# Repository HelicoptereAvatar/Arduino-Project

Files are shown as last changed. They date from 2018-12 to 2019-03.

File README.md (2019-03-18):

# Projet Arduino
Helicoptère Avatar

Lien de la phase de finition de l'usinage: https://youtu.be/9hvU3ZJVlw8

Lien du systeme palonnier/axe moteur version 1: https://www.youtube.com/watch?v=DUoeanbGZsc

Lien du système palonnier/axe moteur version2: https://www.youtube.com/watch?v=2ytFxMqF1lg

Lien du test des moteurs brushless après rectification des soudures: https://www.youtube.com/watch?v=3YJs_jeSbtI7

Lien du 1er Test de décollage du bicoptère via Bluetooth: https://www.youtube.com/watch?v=y_h1CxXEg0Y&feature=youtu.be

Lien du 2eme Test de décollage du bicoptère via Bluetooth: https://www.youtube.com/watch?v=23QDOOEaW0g

Lien de l'orientation du sens de rotation du bicoptère via Bluetooth: https://www.youtube.com/watch?v=-SvJQlqzLKM 

Lien du dernier vol avant la présentation, vol parfait: https://www.youtube.com/watch?v=pWN4PxkNXiw&feature=youtu.be

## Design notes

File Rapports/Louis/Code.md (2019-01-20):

/* Here is the code that I used to control the servos and the ESCs via Bluetooth */

#include <Servo.h>
#include<SoftwareSerial.h>
#define RX 10
#define TX 11
SoftwareSerial BlueT(RX,TX);
char Data;
int PWM=190;
int Angled=90;
int Angleg=90;
Servo esc1;   // Création de l'objet permettant le contrôle de l'ESC
Servo esc2;
Servo servo1;
Servo servo2;

void setup() {
   servo1.attach(2);
   servo2.attach(3);
   servo1.write(90);
   servo2.write(90);
   esc1.attach(6); // On attache l'ESC au port numérique 9 (port PWM obligatoire)
   esc2.attach(5);
   delay(15);
   //Serial.begin(9600);
   BlueT.begin(9600);
   // Initialisation de l'ESC
   //  (certains ESC ont besoin d'une "procédure d'initialisation"
   //   pour devenir opérationnels - voir notice)
   esc1.write(0);
   esc2.write(0);
   delay(1000);
   esc1.write(180);
   esc2.write(180);
   delay(1000);
   esc1.write(0);
   esc2.write(0);

   // Quelques informations pour l'utilisateur
   /*Serial.println("Saisir un nombre entre 0 et 179");
   Serial.println("(0 = arret - 179 = vitesse maxi");
   Serial.println(" demarrage a partir de 20)");*/
   }
 
void loop() {
  if (BlueT.available()){
    Data=BlueT.read();
    if(Data=='A'){
      PWM=BlueT.parseInt();
    }
    if (PWM>0){
      esc1.write(PWM);
      esc2.write(PWM+7);
      delay(5);
    }
    else{
      esc1.write(PWM);
      esc2.write(PWM);          
      delay(5);
      }
    if (Data=='D'){ //Angle entre 75deg et 120deg
        Angled=BlueT.parseInt();
        servo1.write(Angled);
        delay(5);
    }
    if (Data=='G'){  //Angle entre 30deg et 120deg
      Angleg=BlueT.parseInt();
      servo2.write(Angleg);
      delay(5);
  }
  }
}

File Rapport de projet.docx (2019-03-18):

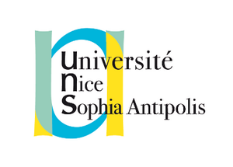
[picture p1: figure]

Rapport de projet

Hélicoptère avatar

Calendini-Clouvel

Encadrant : Monsieur Pascal Masson

Ecole Polytechnique Universitaire de Nice Sophia-Antipolis, 1645 route des Lucioles,

Parc de Sophia Antipolis, 06410 BIOT

# Remerciements

Nous voudrions remercier Monsieur Philippe Duroure (entreprise : 2iADP) pour son aide précieuse dans la réalisation de l’usinage d’une partie du châssis ainsi que Monsieur Xavier Esa (entreprise : DEBARGES) pour nous avoir aidés lors de l’usinage des palonniers.

Nous tenions à remercier particulièrement Monsieur Pascal Masson (enseignant en électronique) ainsi que Monsieur Nassim Abderrahmane pour leurs conseils avisés tout au long de l’avancement du projet.

# Table des matières

# Introduction

Nous présentons dans ce rapport notre projet d’Electronique de deuxième année d’étude. Ce projet consiste à concevoir et réaliser, en binôme, dans un temps imparti, un bicoptère. Nous détaillerons les étapes permettant d’atteindre nos objectifs, à savoir l’envol et la stabilité du système.

We are going to present you in this report our electronic project which goal is to conceive and realise, in pairs and in three months, a dualcopter. You will see all the steps we went through to reach our intent, namely taking off and being stable.

# Matériel utilisé

Afin de pouvoir réaliser ce projet, nous avons utilisé le matériel suivant :

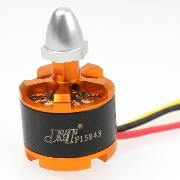
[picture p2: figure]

- 2 moteurs brushless, 920 kv

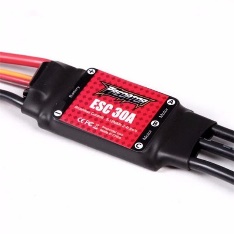
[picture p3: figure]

- 2 ESCs de 30A

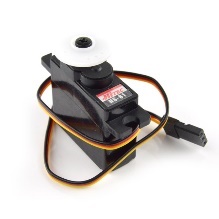
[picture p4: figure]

- 2 servo-moteurs hitech
- 1 châssis dont une partie réalisée sur un centre d’usinage (CNC)

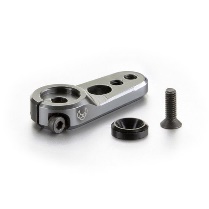
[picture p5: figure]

- 4 palonniers (dont 2 usinés)

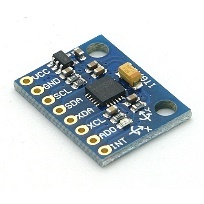
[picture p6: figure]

- 1 accéléromètre/gyroscope GY-521
- 1 carte arduino

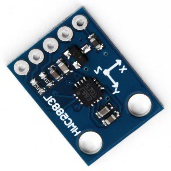
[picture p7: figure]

- 1 magnétomètre

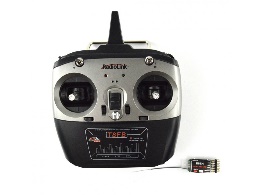
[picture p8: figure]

- 1 émetteur/récepteur radio

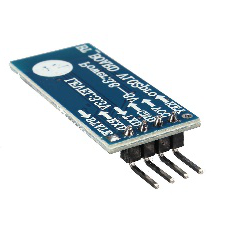
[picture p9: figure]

- 1 module bluetooth

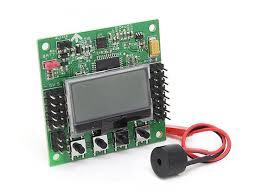
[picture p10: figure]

- 1 carte de contrôle KK2.1.5
- 1 tube en aluminium
- 2 hélices

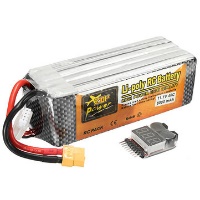
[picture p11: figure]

- 3 batteries Lipo, 3S (12V)
- 1 batterie 5V

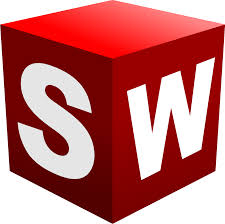
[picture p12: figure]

- Logiciel SolidWorks

# Déroulement du projet

## Conception

Le premier mois, nous avons défini notre stratégie de définition, d'étude et de réalisation, après réflexion nous nous sommes mis d’accord pour diviser le projet en 2 parties, l’électronique et la mécanique. Dans un premier temps nous avons rassemblé les informations nous permettant de comprendre le fonctionnement de ce système et pouvoir appréhender des solutions technologiques répondant aux contraintes.

Après avoir défini les mouvements nécessaires à l’orientation du bicoptère dans l’espace, nous avons dessiné la partie du châssis permettant la rotation des moteurs. Le premier schéma s’est fait sur papier puis sur SolidWorks pour permettre la réalisation sur un centre d’usinage numérique 3axes.

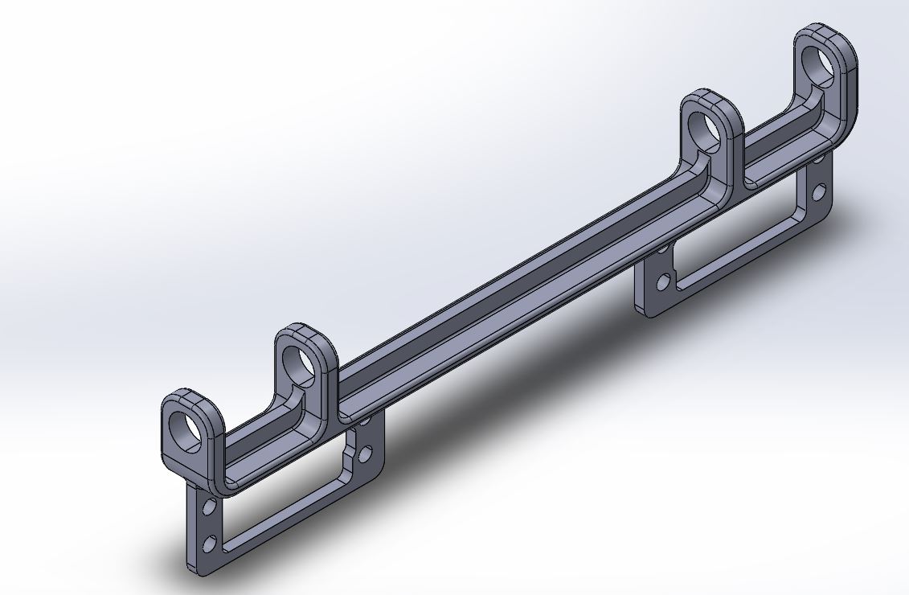
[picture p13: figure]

## Réalisation

### Electronique :

1. Moteurs et servo-moteurs :

Info PWM (Pulse Width Modulation) : Le PWM utilisé doit avoir une fréquence de 50Hz et c’est la durée du temps haut qui permet de coder la vitesse de rotation des moteurs :

- Pour un temps haut de 1000ms les moteurs seront éteints.

- Pour un temps haut de 2000ms les moteurs seront en vitesse max.

Les signaux PWM de 50Hz sont très utilisés en modélisme pour le contrôle de tout type de moteur. En Arduino, la librairie Servo.h permet de générer ces signaux.

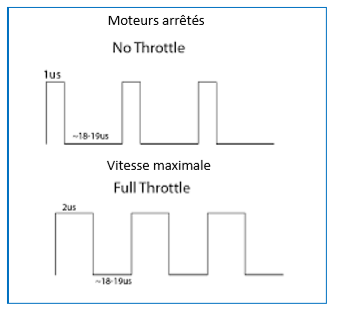
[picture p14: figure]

Nous avons commencé par coder les moteurs brushless et les servo-moteurs mis à notre disposition. Grâce aux éléments de cours ainsi que nos recherches sur internet, nous avons rapidement maitrisé cette technique.

On a ensuite ajouté le module Bluetooth afin de permettre le contrôle à distance de chaque composant.

Une fois les codes mis en commun, nous avons rencontré un premier problème : les servo-moteurs et les moteurs utilisant la même librairie, on ne pouvait contrôler qu’un seul élément à la fois.

Grâce à la documentation Arduino, nous avons compris que cela venait des ports de sortie. Il suffisait juste de brancher les composants sur des ports bien choisis.

2. Asservissement :

Le PID est un système de contrôle permettant la stabilisation de notre bicoptère. Celui-ci agit en fonction des valeurs d’angle que l’accéléromètre et le magnétomètre peuvent fournir.

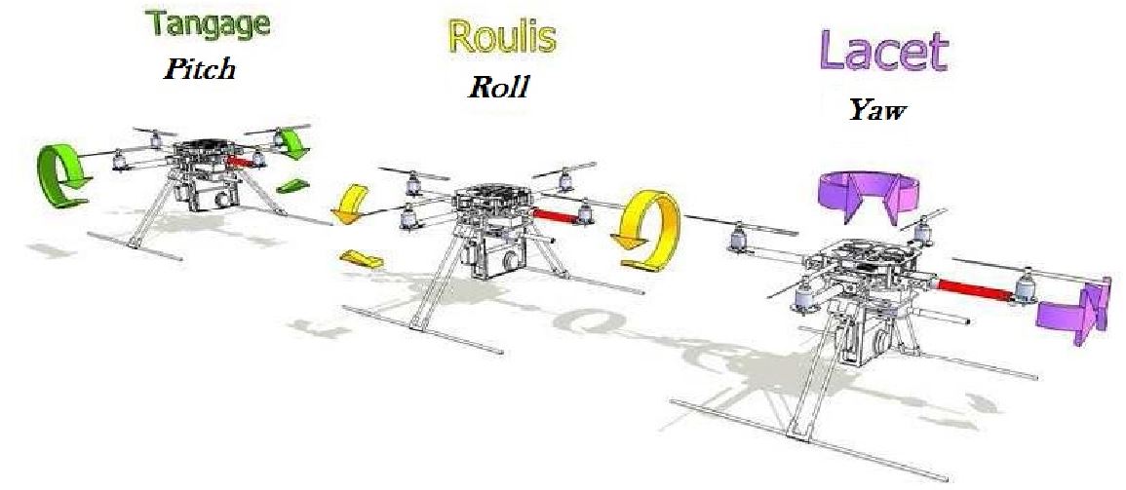
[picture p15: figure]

Dans notre cas, l’axe x correspond au Roulis, l’axe y au Tangage et l’axe z au Lacet

La stabilisation doit se faire suivant l’axe x, y et z. Pour ce qui est des axes x et y nous avons utilisé l’accéléromètre. Celui nous permet d’avoir l’angle (entre 0 et 90°) que fait le bicoptère avec le sol suivant ces 2 axes. Ces informations sont ensuite envoyées au PID et celui-ci va permettre la stabilisation, grâce à trois asservissements :

• Proportionnel

• Intégral

• Dérivé

L’asservissement proportionnel est le plus important, les autres asservissements permettent de gérer les erreurs afin que la stabilisation soit optimale.

Dans notre cas, pour l’axe x, le PID va agir sur les moteurs. En effet, lorsque le bicoptère va pencher vers la gauche, le moteur de gauche va accélérer en conséquence afin de le remettre droit, et inversement.

Pour l’axe y, le PID agit sur les servo-moteurs. Lorsque le bicoptère penche vers l’avant, les servos s’orientent vers l’arrière, ce qui permet à ce dernier de rester parallèle au sol.

La stabilisation sur ces 2 axes a été correctement codée.

Pour la stabilisation suivant z, le PID va recevoir un angle du magnétomètre et non de l’accéléromètre (celui-ci ne permet pas d’avoir la valeur de l’angle du lacet).

Le magnétomètre est en réalité une boussole, le zéro correspond au Nord puis en fonction de comment on tourne notre magnétomètre, l’angle varie entre 0 et 360°.

Pour cet axe z, le PID va agir sur les servos encore une fois mais dans ce cas, il les orientera dans le sens opposé, afin que la rotation soit compensée et que le bicoptère ne tourne pas sur lui-même.

La stabilisation suivant z n’a pas pu se faire car cela devenait trop compliqué pour nous.

### Mécanique :

Après avoir dessiné sur le logiciel de CAO (Conception assistée par Ordinateur ici SolidWorks) la partie du châssis à usiner dans un bloc d’aluminium il faut maintenant ouvrir ce document dans un logiciel de FAO (Fabrication Assistée par Ordinateur ici TopSolid) afin de générer un parcours d’outils pour chaque phase de l’usinage (Ebauche, Semi-finition, Finition) qui sera envoyé au centre d’usinage à commande numérique 3axes.

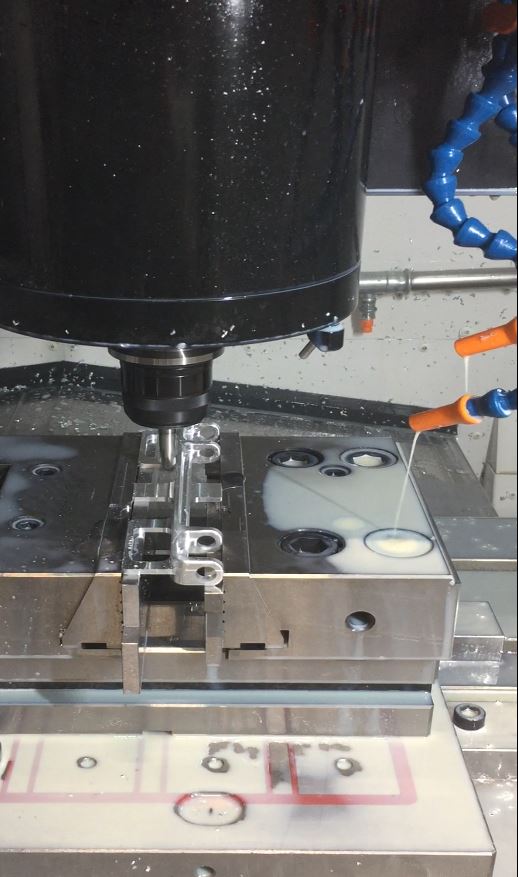
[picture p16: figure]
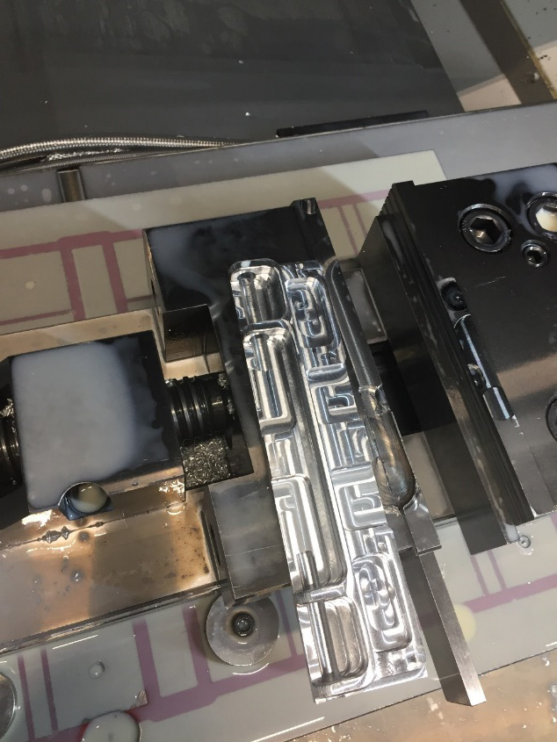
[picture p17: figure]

Nous avons dans le même temps dessiné les palonniers des arbres des moteurs brushless qui permettent par un montage en chappe, d'une rotule et d’un servo-moteur l’orientation de ces moteurs.

Ensuite nous avons sollicité le Fablab et leur imprimante 3D pour réaliser ces derniers puis notre professeur nous a fourni un squelette de drone que nous avons adapté à la partie déjà usinée.

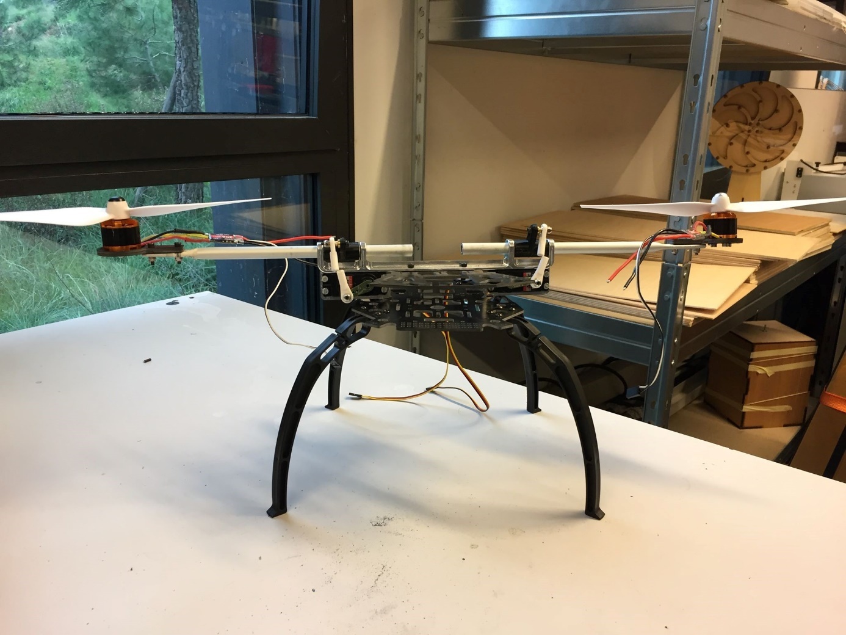
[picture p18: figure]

# Mise en commun

Une fois l'assemblage mécanique réalisé, nous avons intégré l’électronique, puis paramétrer l’amplitude d’action des servo-moteurs pour ne pas endommager les liaisons mécaniques. Dans la mesure où notre projet est soumis à la gravité, nous avons équilibré les composants pour que le centre de gravité soit le plus proche de l’axe des moteurs~~.~~

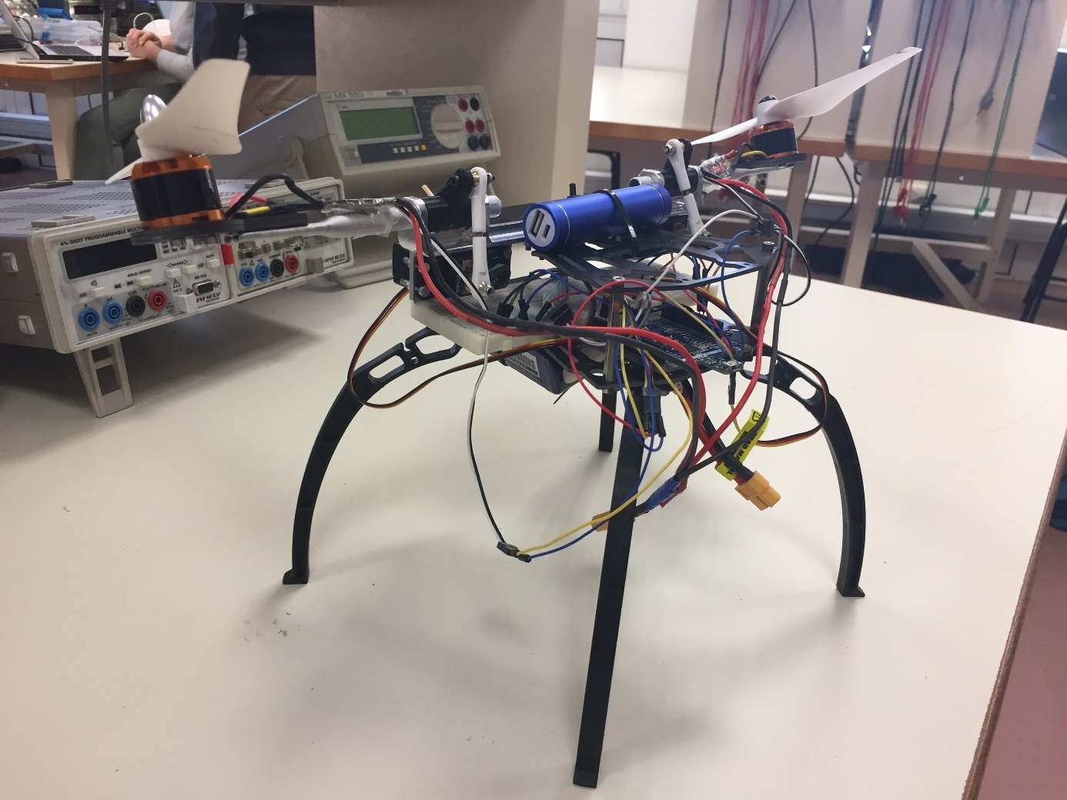
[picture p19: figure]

# Problèmes rencontrés

## Problème lié au Bluetooth :

Nous avons contrôlé le drone avec un module Bluetooth connecté à un téléphone. Cette connexion n’était pas assez rapide et instable, en effet les modules Bluetooth peuvent changer de canal jusqu’à 1600 fois par seconde. Le drone devenait ainsi incontrôlable et difficile à commander. Les composants électroniques étaient mal gérés ce qui provoquait beaucoup de saccades.

Pour régler ce problème, nous avons donc opté pour une radiocommande de modélisme, ce qui nous a permis d’avoir une connexion adaptée aux besoins qu'exige notre système. Après avoir développé un code dont nous avons trouvé la base sur internet nous sommes parvenus à mettre au point notre ensemble.

Finalement notre code Arduino comporte 2 fonctions principales :

- La boucle comprenant le PID
- Une fonction permettant le contrôle de la télécommande

## Problème lié à la stabilisation :

Nous n’avons pas réussi à régler le problème de la stabilisation suivant z (Lacet). Après de nombreuses recherches, nous avons décidé de changer de carte, avec l’accord de notre professeur. Cette carte, la Hobbyking KK2.1.5, nous permet, en la paramétrant complètement, de gérer la stabilisation suivant les 3 axes.

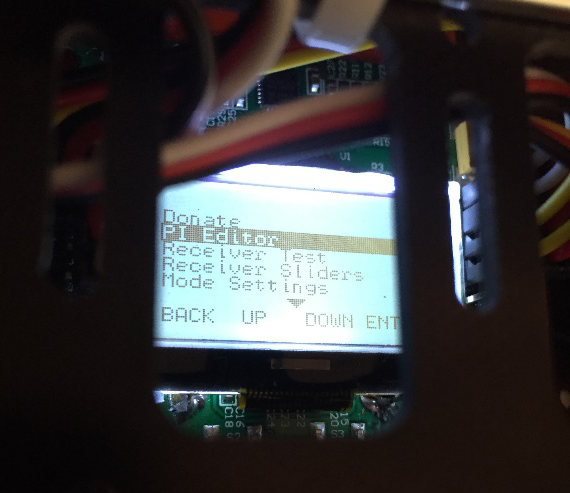
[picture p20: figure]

Une fois la carte en configuration d’usine il faut préciser quelles sont les entrées et sorties utilisées. Puis définir notre système (pour nous ce sera donc un bicoptère) et régler tous les paramètres c’est-à-dire les constantes du PID (cette carte ne permet de régler que la proportionnelle et l’intégrateur ce qui s’avèrera suffisant par la suite). Enfin il faut réaliser de très nombreux tests de vol afin d’affiner les réglages du PID et de prendre notre système en main (ce qui n’est pas évident).

## Problème lié au jeu dans la liaison mécanique :

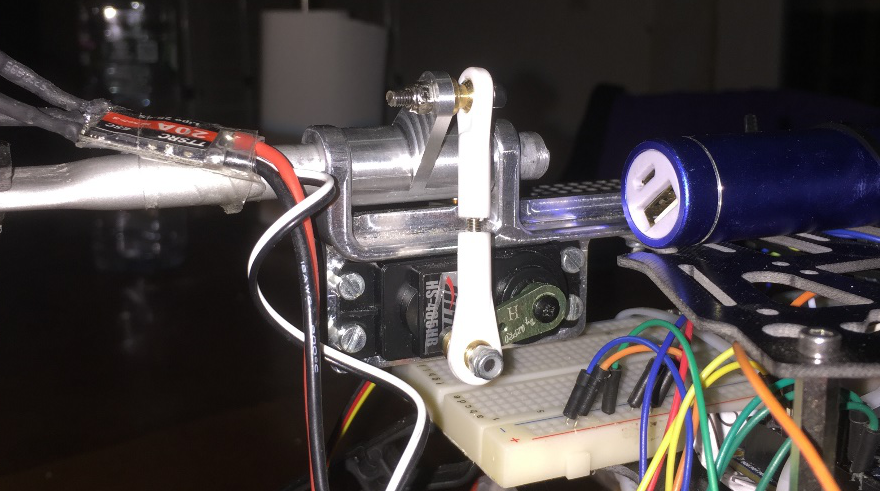
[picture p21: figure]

Les palonniers des arbres moteurs imprimés au Fablab ont une précision assez mauvaise et cela a engendre un jeu important dans l’orientation des brushless, rendant le bicoptère très instable. Nous avons donc réalisé ces palonniers au centre d’usinage dans un bloc d’aluminium pour avoir une précision bien meilleure et donc un jeu quasiment nul. Nous avons dessiné les palonniers sur le logiciel de CAO et en passant par un logiciel de FAO puis nous avons réalisé ces pièces sur le centre d’usinage 5axes.

Et voici le résultat final de la liaison mécanique :

# Conclusion

Ce projet nous a permis d’apprendre beaucoup de choses dans différents domaines, et nous appris à être autonome.

Après 3 mois de travail, notre bicoptère remplit la fonction principale de notre cahier des charges qui est de voler stablement.

Certaines fonctions contraintes sont aussi vérifiées, la résistance à l’environnement à été prouvée car même après environ 30 chutes le système est toujours intact. La sécurité est suffisante car il faut faire une manipulation spéciale pour « armer » le système (maintenir les deux joysticks de la radiocommande dans le coin inférieur gauche pendant quelques secondes), de plus le système se désarme automatiquement après 20 secondes d’inactivité. Cependant le drone n’est pas autonome car les moteurs brushless ne sont pas assez puissants pour soulever le drone (670grammes) plus une batterie (330grammes), les vols ont été effectués grâce à une alimentation secteur.

Nous sommes très satisfaits du résultat obtenu, bien qu’environ 200 heures ont été nécessaires à la réalisation de ce projet, il peut encore être perfectionné, au niveau de l’esthétique et de l’autonomie. Cela sera sûrement fait d’ici la fin de l’année scolaire.

Voici une vidéo du système final en vol : https://www.youtube.com/watch?v=pWN4PxkNXiw&feature=youtu.be

# Annexes

## Cahier des charges

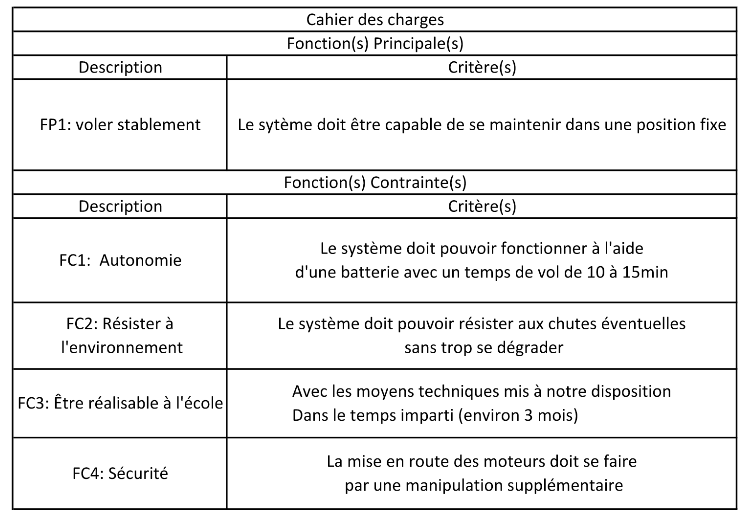
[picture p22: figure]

## Planning

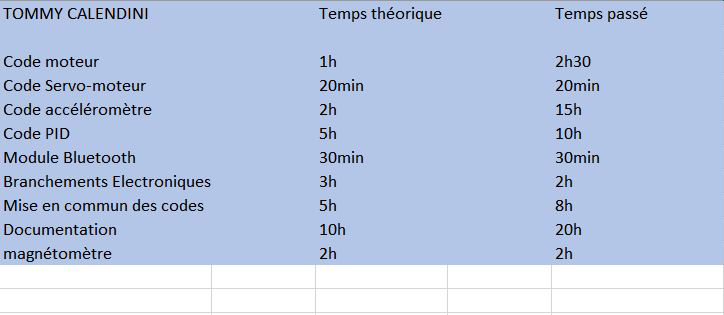
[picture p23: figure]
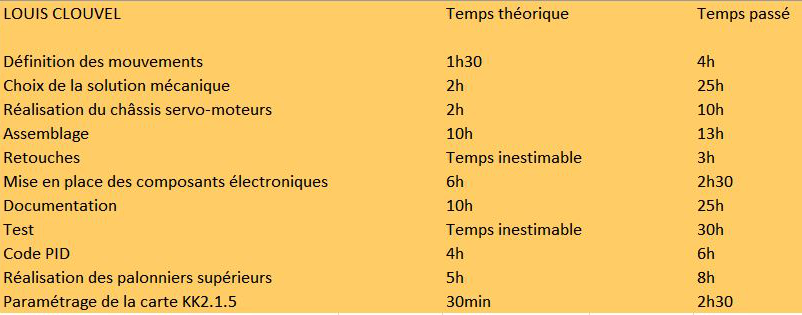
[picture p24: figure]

## Bibliographie

En ce qui concerne la documentation sur les fonctions et composants Arduino nous avons utilisé ce site : https://www.arduino.cc/

Lors du commencement du projet, ce forum nous a bien éclairé sur la conception du bicoptère : https://www.helicomicro.com/2013/08/31/walkera-pandora-warrior/

Le squelette du code de la radio commande nous a été expliqué et nous avons pu le récupérer sur ce forum : https://www.firediy.fr/article/utiliser-sa-radiocommande-avec-un-arduino-drone-ch-6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

Pour ce qui est du choix de la carte électronique qui est maintenant sur le bicoptère ces deux pages web nous ont contribué au bon choix de carte :

https://www.youtube.com/watch?v=jRPUO8T1Iwk

https://www.instructables.com/id/Bicopter-Dualcopter/

Nous vous mettons le lien de notre chaine Youtube pour que vous puissiez votre l’avancement en vidéo de notre projet : https://www.youtube.com/channel/UC59cZ8Wts5xyrMVUgzJZBDQ/videos?view_as=subscriber

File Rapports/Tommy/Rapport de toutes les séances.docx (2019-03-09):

Rapport de séance : le 10 décembre 2018

Soudage et mise en marche des moteurs :

La semaine dernière, Louis et moi avons débuté le projet ne mettant en marche nos 2 moteurs brushless. Pour cela, nous avons tout d’abord commencé par souder les moteurs aux esc comme le montre l’image ci-dessous. Nous avons dû nous y reprendre à deux fois, en raison d’une erreur au niveau des branchements.


Ensuite, après réalisation du montage comprenant :

-Les moteurs,

-les esc,

- une batterie LiPo,

-et la carte arduino

Et grâce à un code trouvé sur internet, nous avons pu faire fonctionner les 2 moteurs. Seulement avec ce code, la vitesse des moteurs est définie à l’aide du moniteur série, il devra donc être modifié par la suite pour correspondre à nos besoins.

Prise d’informations et réalisation d’une pièce sur SolidWorks :

Durant la séance d’aujourd’hui, pour ma part, j’ai seulement pris connaissances de l’accéléromètre et du PID (Proportionnel Intégral Dérivé) car cela va jouer un rôle important dans le projet. J’ai pu en comprendre le fonctionnement et avoir une idée des programmes à réaliser même si cela reste compliqué. Je pense que j’accentuerai mes recherches pour comprendre la chose au mieux (à l’aide de vidéos, d’exemples etc..). Au départ je pensais que le PID jouait lui-même le rôle de l’accéléromètre mais en me documentant j’ai pu comprendre que ce n’était pas le cas. J’ai pu comprendre que l’accéléromètre nous permettra de connaître l’orientation de notre hélicoptère (la valeur des angles suivant x, y, z) et le PID nous permettra lui de gérer la stabilité de l’hélicoptère.

De son coté, Louis à modélisé sur le logiciel SolidWorks, d’une part les servomoteurs, et le système empêchant l’arrachement des servomoteurs et d’autre part, la pièce permettant la rotation des axes des supports moteurs.

Commande :

Nous avons commandé des hélices, et des servomoteurs et nous envisageons de commander une plaque de distribution PCB.

Rapport de séance du 17 Décembre 2018

Lors de cette séance je me suis surtout intéressé à l’accéléromètre. J’ai demandé l’acquisition d’un accéléromètre GY-521, celui-ci étant plus adapté à notre projet dans la mesure où il contient un gyroscope 3 axes. J’ai commencé par souder les pattes, pour pouvoir effectuer les branchements par la suite.


J’ai ensuite regardé le code, j’ai réussi à trouver un bout de code sur internet permettant d’obtenir la valeur de l’angle suivant l’axe y. J’ai donc rajouté du code pour pouvoir avoir la valeur de l’angle suivant les 3 axes (x,y,z).

De son côté Louis est tout d’abord parti chercher un colis contenant des chappes à rotule, 2 palonniers et une tige filetée. Nous avons agrandi grâce à une perceuse le trou d’un des palonniers pour pouvoir mettre en place la tringlerie, Louis s’est chargé de la mise en place. Il a également fixé les moteurs sur les supports.


Compte rendu de ces vacances

Durant ces vacances j’avais pour objectif de regarder les codes en rapport avec la stabilisation de l’hélicoptère. C’est-à-dire les codes de l’accéléromètre et du PID. J’avais déjà trouvé les codes de l’accéléromètre sur internet avant les vacances mais ceux-ci se sont supprimés. J’ai donc utilisé le cours fourni pour faire moi-même le code et ainsi mieux comprendre ce que je fais.

Je me suis ensuite penché sur le PID qui reste une notion assez complexe. J’ai vu à travers quelques vidéos comment celui-ci fonctionnait mais il m’a été très difficile de trouver un code. J’ai contacté un passionné de modélisme présent en corse pour avoir quelques informations et pour poser certaines questions. Lorsque je lui ai parlé du PID il m’a tout de suite parlé de la carte multi Wii qui intègre déjà ces éléments. J’ai également remarqué que c’était le cas des cartes ardu copter. Cependant j’aimerai essayer de coder le PID avec Arduino, et si vraiment cela devient trop compliqué je penserai à cette alternative. En tout cas, j’ai trouvé d’un code permettant de gérer la stabilisation suivant un seul axe. Il faudra qu’on le teste, en espérant que cela marche. Cela permettra d’avoir une bonne base.

Voici le code :


Bien évidemment, le code utilise les valeurs données par l’accéléromètre.

J’ai également modifié le code pour contrôler les moteurs afin que l’on puisse désormais les contrôler par Bluetooth. Pour cela j’ai utilisé un code déjà réalisé lors des TD :


Que j’ai modifié pour qu’il corresponde au problème :


La également, il manque plus qu’à le tester.

Compte rendu des journées suivantes : 07/01/2019 et 08/01/2019

Journée du 07/01

Les tests pour valider le programme permettant de contrôler les moteurs grâce au module Bluetooth ont été réalisés et sont concluants, j’ai tout de même dû trouver les valeurs minimales et maximales du moteur (par tâtonnement) (min = 46 max = 163). J’ai ensuite adapté le programme pour pouvoir commander les servos-moteurs à distance.

En ce qui concerne le PID nous avons obtenu le mail d’un professeur du département Elec possédant un balancier permettant de le tester, nous allons donc prendre contact avec lui pour savoir si le programme fonctionne.

Louis quant à lui est allé au fablab pour demander au professeur d’imprimer à l’aide de l’imprimante 3D les palonniers des axes moteurs.


Il a ensuite récupéré le squelette d’un drone inutilisé pour l’adapter au châssis contenant les servos moteurs. Il a fallu faire quelques découpes et enlever les pièces dont nous n’aurions pas besoin.


Il a également mesuré l’entraxe des trous que nous allions utiliser sur le squelette pour les reporter sur le châssis. Il ne restera plus qu’à les pointer et percer.

Dès la fin du cours nous sommes allés au FABLAB tous les deux pour récupérer les palonniers et assembler le squelette découpé et le châssis des servos-moteurs.

Petit problème : la cote du rayon interne de chaque palonnier était trop petite de 0.5mm. Nous avons essayé d’agrandir les diamètres à l’aide de la perceuse à colonnes.

Ils n’ont malheureusement pas résisté aux efforts et ont cassé. Nous avons alors modifié la cote demandée de 0.6mm pour palier à l’erreur de fabrication. L’impression aura lieu dans la nuit.

Nous avons alors percé le châssis aux endroits repérés précédemment pour pouvoir le fixer au squelette récupéré et déjà modifié.

Il a ensuite fallu aplatir et percer l’extrémité du tube cylindrique. Cette surface aplatie permettra de fixer les supports moteur (plans) à chaque tube. Nous avons pris une longueur de tube totalement arbitraire pour le moment qui pourra être modifiée par la suite. Le tube a été coupé à l’aide d’un coupe tube.

Voici le rendu du système à la fin de la journée :


Journée du 08/01/2019 :

Nous sommes allés au FABLAB à partir de 13h.

Après avoir récupérer les palonniers qui s’adaptent finalement aux tubes, nous avons fixé les chappes à rotule sur les palonniers et raccourci les vis.


Il fallait maintenant rendre les servos-moteurs et le châssis solidaire, nous avons alors raccourci 8 vis car elles étaient beaucoup trop longues et nous les avons limées pour rendre le début du pas de vis utilisable et propre.


La touche finale : plaquer la partie supérieure du squelette sur le châssis. Et c’est encore la même histoire pour les vis. Tout raccourcir, limer et visser.

Tout à été fixé à l’aide d’écrous freins, certes plus lourds, ils permettront de maintenir au mieux les composants qui vont subir beaucoup de vibrations durant le vol. Des écrous classiques se desserreraient et alors tout se désolidariserait.

Voici les images du résultat à la fin de la journée, la partie inférieure n’est pas fixée.


Il reste maintenant à rendre solidaire les deux chappes à rotule, surélever la partie supérieure de la partie inférieure du squelette (à l’aide de tasseaux) et déterminer de chaque composant électronique. Nous avons aussi besoin d’une plaque de distribution PCB pour les ESCs et de l’accéléromètre.

Rapport de séance

Assemblage

Lors de cette séance nous avons tout d’abord commencé par fixer le palonnier restant à l’axe du moteur (Louis avait déjà fixé le second palonnier de son côté). Pour cela nous avons percé le palonnier ainsi que l’axe du moteur afin de pouvoir les lier entre eux à l’aide d’un axe (pour le moment nous utilisons un cure-dent). Nous avons également pensé à percer l’axe du moteur sur le coté et non en plein milieu. En effet, lorsque nous percions au milieu, l’orientation vers l’avant était bien plus faible et que l’orientation vers l’arrière.

Nous avons également raccourci les axes moteurs à l’aide d’une scie car ceux-ci étaient bien trop long.

Code

Nous nous sommes ensuite intéressés au code. Nous avons tenté de mettre dans un même programme le code des moteurs et celui des servo-moteurs. Seulement nous avons eu un problème, comme les deux codes utilisent le même Timer, ils ne pouvaient être exécuté en même temps. Nous avons donc essayé de télécharger la librairie Timer2 qui normalement permet de résoudre ce problème mais cela n’a pas marché, on ne pouvait pas téléverser. Nous allons nous appuyer sur le sujet afin de trouver une solution.

Enfin nous avons fait les branchements et modifié le code des moteurs afin de pouvoir les contrôler les deux en même temps. Comme un des moteurs allait plus vite que l’autre, Louis a mis une petite ‘avance’ à l’autre moteur afin de compenser. L’exécution du programme nous a permis de faire décoller l’hélicoptère de quelques millimètres, ce n’est pas grand-chose mais c’est tout de même assez satisfaisant. Comme la stabilisation n’est pas mise en place, dès que l’hélicoptère se soulevait du sol il partait sur un côté. Mais cela reste assez prometteur.

La vidéo du « décollage » a été mise sur le github.

Rapport de séance

Ce que l’on a fait pendant les vacances :

Avant les vacances, nous avons testé pour la première fois le code du PID que j’avais trouvé et modifié lors des vacances de Noël et contre toute attente, cela fonctionnait. La stabilisation était suivant l’axe x, ainsi lorsque l’hélicoptère penchait vers la droite, le moteur de gauche accélérait de façon que l’hélicoptère se stabilise et inversement. Nous avons codé le PID suivant l’axe y ou là, le PID agissait sur les servo-moteurs. Cela a également fonctionné, ce qui nous a permis d’avancer et de mettre en commun le code du PID et du module Bluetooth. Nous avons pris une vidéo ou l’on peut voir le PID en action, Louis va normalement mettre la vidéo sur le GitHub.

Nous avons ensuite essayé de le faire voler mais en raison de la faible efficacité du Bluetooth et des constantes du PID non optimales, l’hélicoptère s’est renversé à chaque essaie.

Aujourd’hui :

Pour pallier le problème du Bluetooth, nous avons demandé une radiocommande. Louis s’est chargé du code et il a fait du très bon travail, il a réussi à trouver un premier code sur internet assez clair qu’il a ensuite modifié pour qu’il corresponde à nos besoins. Nous arrivons désormais à contrôler l’hélicoptère à l’aide de cette radiocommande. Malheureusement, après quelques essaies, nous n’avons pas réussi à le faire décoller. Les moteurs ne semblent pas assez puissants et il manque toujours la stabilisation suivant z. J’ai passé ma séance a essayé de trouver un bon code clair pour avoir la valeur de l’angle suivant l’axe z mais je n’ai pas réussi, j’ai essayé plusieurs choses qui n’ont pas marché, je pense que cela va nous poser beaucoup de problème.

Rapport de séance

Ces derniers temps, la stabilisation suivant z me posait un problème. En effet, j’avais pour objectif de trouver comment avoir l’angle suivant z mais je ne trouvais aucun code. J’ai donc compris que l’accéléromètre était incapable d’obtenir l’angle du lacet (suivant z) et qu’il fallait utiliser un autre composant, qui est le magnétomètre et qui utilise une boussole. Après avoir obtenu le composant, j’ai commencé par souder les pattes, ayant fait quelques erreurs de soudage, monsieur Masson m’a expliqué comment bien souder. Je me suis ensuite attaqué au code. J’ai trouvé plusieurs codes mais cela ne fonctionnait pas, les valeurs affichées dans le moniteur série ne variaient pas. J’ai donc continué mes recherches et j’ai vu que le composant que j’avais n’était pas le HMC5883L comme affiché dessus mais le QMC5883L. J’ai donc utilisé le code correspondant à ce composant et cela a marché. On obtient bien l’angle du lacet en degré.

Explication PID, accéléromètre et magnétomètre

Le PID est un système de contrôle permettant la stabilisation de notre hélicoptère. Celui-ci agit en fonction des valeurs d’angle que l’accéléromètre et le magnétomètre peuvent fournir.

La stabilisation doit se faire suivant l’axe x, y et z. Pour ce qui est des axes x et y nous avons utilisé l’accéléromètre. Celui nous permet d’avoir l’angle (entre 0 et 90°) que fait l’hélicoptère avec le sol suivant ces 2 axes. Ces informations sont ensuite envoyées au PID et celui-ci va permettre la stabilisation, grâce à trois asservissements :

- Proportionnel
- Intégral
- Dérivé

L’asservissement proportionnel est le plus important, les autres asservissements permettent de gérer les erreurs afin que la stabilisation soit optimale.

Dans notre cas, pour l’axe x, le PID va agir sur les moteurs. En effet, lorsque l’hélicoptère va pencher vers la gauche, le moteur de gauche va accélérer en conséquence afin de le remettre droit, et inversement.

Pour l’axe y, le PID agit sur les servo-moteurs. Lorsque l’hélicoptère penche vers l’avant, les servos s’orientent vers l’arrière, ce qui permet à l’hélicoptère de rester parallèle au sol.

La stabilisation sur ces 2 axes a été correctement codé, il manque juste à modifier les constantes du PID pour avoir la meilleure stabilisation possible mais cela nécessite que l’on fasse des tests de vol (impossible pour le moment).

Il nous reste maintenant à coder le PID pour gérer la stabilisation suivant z. Cette fois-ci le PID va recevoir un angle du magnétomètre et non de l’accéléromètre (celui-ci ne permet pas d’avoir la valeur de l’angle du lacet).

Le magnétomètre est en réalité une boussole, le zéro correspond au Nord puis en fonction de comment on tourne notre magnétomètre, l’angle varie entre 0 et 360°.

Pour cet axe z, le PID va agir sur les servos encore une fois mais dans ce cas, il les orientera dans le sens opposé, afin que la rotation soit compensée et que l’hélicoptère ne tourne pas sur lui-même.

Rapport de séance

Au cours de cette séance, Louis a tout d’abord commencé par m’expliquer comment la nouvelle carte fonctionnait, dans la mesure où je ne l’avais pas encore testé. Il m’a expliqué comment faire le calibrage, comment modifier les valeurs des moteurs, des servo-moteurs, les constantes du PID etc…

Ensuite comme nous avions reçu deux nouveaux esc, de 30 ampères, nous avons entamé le remplacement. On a donc dû faire 10-15 min de soudure, afin de dessouder les anciens et de souder les nouveaux.

Louis avait un problème pour contrôler les servo-moteurs et après réflexion, nous nous sommes rendu compte que cela était dû à la batterie. Celle-ci était en effet déchargée. Une fois remplacé, tout fonctionnait comme il faut.

Nous avons finalement réalisé des tests de vols plutôt prometteur. Nous avons modifié les constantes du PID afin de permettre le vol. Etant parti manger je n’ai pas pu assister au premier envol de notre hélicoptère (un peu déçu) mais j’ai eu pu voir la vidéo. C’est une satisfaction. La vidéo sera mise sur le GitHub par Louis ces prochains jours.

Rapport de séance

Le projet étant fini, lors de cette séance nous n’avons pas fait grand-chose. Nous avons avancé le PowerPoint pour l’oral de la semaine prochaine en majorité. Nous avons quand même ressoudé quelques parties de l’hélicoptère. Nous avons essayé d’utiliser des fils souples pour l’alimentation secteur mais ceux-ci ne permettaient pas une puissance maximale, l’hélicoptère ne pouvait ainsi pas décoller. Nous sommes donc revenus sur les fils de départ. Puis nous avons fait quelques tests de vol, pour mieux prendre en main le bicoptère.

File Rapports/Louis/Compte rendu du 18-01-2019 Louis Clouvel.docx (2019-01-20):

Compte rendu du 18/01/2019

Le but aujourd’hui était de remplacer le moteur défectueux, de pouvoir commander servo-moteurs et les moteurs brushless ainsi que de pouvoir le commander sans être branché à l’ordinateur.

J’ai donc commencé par régler ce problème de commande au niveau du code pour m’apercevoir que les pins 5 et 6 de la carte Arduino continuaient à délivrer du PWM même lorsque la librairie « Servo » était utilisée (merci à internet et aux professeurs). (Le code utilisé est dans la partie Rapporte/Louis/Code.md de GitHub)

Une fois ce problème réglé j’ai tout de même fait un test sur le bicoptère pour vérifier que dans la pratique cela fonctionnait aussi et c’était le cas. (Après 1h30 de bataille tout de même).(J’ai aussi refait les branchements sur la plaque de distribution car il y avait un beau sac de nœuds avec des fils de la même couleur)

Il faut maintenant remplacer ce moteur défectueux et j’ai pour cela pris le moteur d’un projet d’une année antérieure, seulement il a fallu dessouder des ESCs chaque moteur, les dévisser de leurs supports, remettre de la gaine thermo formable sur chaque fil (pour éviter les courts-circuits) et ressouder tous les fils aux bons endroits. Tout cela m’a pris une bonne heure mais ça y’est les deux moteurs tournaient à peu près à la même vitesse maintenant.

Dernière étape et il ne reste plus qu’environ 30min, vite je récupère une batterie qui délivre 5V pour le fonctionnement de la carte Arduino et des rilsans qui me permettront d’attacher tous les composants au squelette du bicoptère. Et voilà ce que ça donne :


Le drone est maintenant en ordre de marche. Allons tester cela dans le couloir là où il y a bien plus de place.

On commence par mettre les hélices à l’horizontale et augmentons la puissance doucement : https://www.youtube.com/watch?v=23QDOOEaW0g&feature=youtu.be

Ah oui il subsiste un léger décalage dans la vitesse de rotation, ce qui l’empêche d’être stable au décollage mais l’accéléromètre/PID devrait pouvoir gérer cela.

J’ai aussi tenté de faire tourner le bicoptère sur lui-même avec un gain constant pour les moteurs brushless et uniquement en orientant les hélices à l’aide des servo-moteurs : https://www.youtube.com/watch?v=-SvJQlqzLKM&feature=youtu.be

Le test est concluant !

Il reste à s’occuper du code du PID et de l’accéléromètre pour pouvoir stabiliser le bicoptère. (La boucle de stabilisation ne doit pas dépasser 100ms sinon notre système ne réagira pas assez vite et pendant trop longtemps ce qui ne le rendra absolument pas stable

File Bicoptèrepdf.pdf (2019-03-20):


# Bicoptère

CALENDINI TOMMY

CLOUVEL LOUIS

# Cahier des Charges


# Sommaire

### I. Matériaux/Matériel utilisé(s)

- Pour la mécanique


- Pour l’électronique
II. | Déroulement du projet
| • Conception
| • Réalisation
III. | Problèmes rencontrés
| • Lié au Bluetooth
| • Lié à la stabilisation
| • Lié à la mécanique
IV. | Conclusion

# Matériaux utilisés


- Deux blocs d’aluminium
- Un châssis en fibre
- Une tige filetée


- 2 supports moteurs en fibre
- 4 vis pointeau


- Un tube en aluminium
- 4 chapes à rotule
- 4 entretoises en aluminium
- 2 hélices

Au niveau mécanique :

# Matériel utilisé


- 2 moteurs brushless, 920 kv
- 2 ESCs de 30A
- 2 servo-moteurs hitech
- 1 accéléromètre/gyroscope GY-521


- 1 carte arduino
- 1 magnétomètre


- 1 module bluetooth


- 1 émetteur/récepteur radio
- 1 carte de contrôle KK2.1.5
- 1 batterie 5V
- 3 batteries Lipo, 3S (12V)


- 1 alimentation secteur, 12V 12A

Au niveau Electronique :

# Conception


# Conception


# Réalisation


- Electronique :

# Réalisation


- Electronique :

Asservissement

# Réalisation


- Mécanique:

# Réalisation


- Mécanique:

# Réalisation


- Mécanique:

# Réalisation

- Mécanique + Electronique :


# Problèmes rencontrés

Liés à l’électronique :


# Problèmes rencontrés

Liés à la mécanique :

# Problèmes rencontrés


Liés à la stabilisation :

# Conclusion

- Autonomie
- Comprendre le
fonctionnement d’un
bicoptère
- Résultat satisfaisant

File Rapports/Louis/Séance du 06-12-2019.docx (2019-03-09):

Séance du 06/03/2019

Aujourd’hui nous avons réalisé le PowerPoint qui nous servira de support vidéo durant la présentation. Nous avons aussi changé les fils de l’alimentation pour des fils souples seulement ces fils souples avaient une section inférieure aux fils durs, il a fallu doubler ces fils pour que l’intensité nécessaire pour le décollage puisse passer dans ces nouveaux fils.

De plus grâce aux fils souples le bicoptère est très stable, c’est donc une bonne solution !
J’ai pesé le drone sans batterie, il pèse 670grammes, la batterie pesant 330grammes le poids total est de 1000grammes, malheureusement après plusieurs tests, les moteurs ne sont pas assez puissants pour permettre au drone de décoller.

Clouvel Louis

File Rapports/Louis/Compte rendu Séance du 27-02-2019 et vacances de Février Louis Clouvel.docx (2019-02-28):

Compte rendu Séance du 27/02/19 et des vacances de Février

Durant les vacances de Février j’ai profité du fait d’être rentré chez moi pour pouvoir aller usiner les palonniers de l’arbre moteur dans un bloc d’aluminium car ceux fabriqués au Fablab à l’imprimante 3D n’étaient pas assez solides (ils se sont énormément dégradés alors que nous avions une utilisation normale de ces derniers). Pour fixer les palonniers sur les arbres moteur j’ai opté pour la solution de la vis pointeau. (photo ci-dessous)


En vissant dans le palonnier dans lequel passe l’arbre moteur, la vis pointeau va « entrer » dans l’arbre moteur ce qui va rendre solidaire le palonnier et l’arbre moteur. Ce qui nous donne le montage suivant :


En ce qui concerne la partie code, je n’ai pas réussi la boucle d’asservissement pour la stabilité sur l’axe vertical car je ne connaissais pas à quelle vitesse le système tournait sur lui-même. Réagir avec la bonne intensité est donc quasi improbable car soit on va trop incliner les moteurs et le système va tourner dans l’autre sens, soit pas assez et le système continuera à tourner sur lui-même.

J’avais anticipé ce problème quelques semaines auparavant en achetant une carte électronique (KK1.2.5 Control Board), après beaucoup de recherches, qui en la paramétrant correctement me permettra de contrôler le bicoptère plus ou moins parfaitement. Et bonne nouvelle, la carte est arrivée !

J’enlève donc du châssis la carte Arduino, l’accéléromètre, le magnétomètre, la petite batterie 5V et la plaque de distribution. Puis à l’aide de la documentation de la carte électronique en anglais je commence à brancher le récepteur radio, les ESCs et les servo-moteurs sur cette dernière. Et lorsque je tente de mettre la carte en tension, rien ne se passe…. Je fouille donc sur plusieurs forums pour finir par me rendre compte que la carte est alimentée par le câble « retour » des ESCs (la fiche qui contient le byte de commande, une masse et, pour nos ESCs, rien d’autre, pas de petit fil rouge pour les 5V….). J’opte alors pour le système D en dénudant un vieux câble USB sur lequel je libère la masse et le 5V de leur gaine pour pouvoir mettre en contact le pin + de la carte avec le 5V du câble USB et la masse à la masse et TADAM, le petit écran LCD de la carte s’allume. S’en suit des heures de configuration de la carte pour finalement rencontrer un énième problème : les servo-moteurs ne sont pas activés….. je pense alors que le problème vient de l’alimentation et sachant que le professeur doit nous fournir de nouveaux moteurs brushless et ESCs qui ont ce fil + de retour à la carte je laisse le projet après deux journées et demie de travail le projet.

Durant la séance du 27/02/19 nous avons récupéré les ESCs (mais les nouveaux moteurs ne sont pas encore arrivés...) et nous avons donc échangé les ESCs or il a fallu dessouder tous les fils, mettre des cosses males sur les fils de chaque moteur et tout souder à nouveau, et là, comme prévu, lorsque j’ai branché la batterie aux ESCs, la carte s’est mise en tension, et en ce qui concerne les servo-moteurs, ils fonctionnent bien ! Le problème venait donc bien de l’alimentation de la carte.

Puis après avoir fait quelques tests de décollage les batteries étaient vide, nous avons donc emprunté une alimentation secteur au professeur pour nous permettre de continuer ces tests de décollage.


Après 2H de prise en main et modifications, voici le résultat : https://www.youtube.com/watch?v=ciKJTkJsmgA&feature=youtu.be

Bien sûr il faut affiner les paramètre que j’avais entré dans la carte car en prenant en main le bicoptère (ce qui n’est pas des plus évident) je me rend compte que la valeur du proportionnel est trop basse sur le roulis et trop haute sur le tangage(image descriptive des termes roulis, tangage et lacet ci-dessous)


S’en suivent donc de longues heures de mise au point (j’ai passé environ 6h aujourd’hui à prendre en main le bicoptère et à modifier les réglages dans la carte électronique).

Puis tard dans la soirée je repense au fait que le bicoptère ait une tendance à se pencher vers l’avant au décollage puis en « vol », me vint alors l’idée de « greffer » une planchette de bois à l’arrière de ce dernier à l’aide d’une pince à linge (système D encore une fois) qui permettra de faire contre-poids et d’avoir plus d’inertie dans la stabilisation et lors du décollage suivant le problème est presque réglé ! Je renchéris donc en mettant une seconde planchette de bois.


Et là tout va mieux, certes ce n’est absolument pas parfait et les problèmes viennent aussi du pilote du bicoptère (en l’occurrence moi ) mais les réglages ne semblent pas être trop mauvais, on peut toujours faire mieux c’est certain.

Voici une vidéo filmée par moi-même assez tard dans la nuit après que toutes les modifications aient été faites :

https://www.youtube.com/watch?v=xpdm8R63ewo&feature=youtu.be

Je ferais un document texte uniquement pour présenter la carte KK2.1.5.

CLOUVEL Louis

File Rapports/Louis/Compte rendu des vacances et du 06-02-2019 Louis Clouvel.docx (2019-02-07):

Compte rendu des vacances et du 06/02/2019

Durant les vacances nous avons modifié un code de PID basique (trouvé sur internet) pour qu’il soit en adéquation avec notre système. Après avoir eu quelques soucis de Timer nous avons réussi à l’asservir sur l’axe x et l’axe y (c’est-à-dire sur le plan horizontal) autrement dit lorsque le système qui le plan horizontal, il utilise la vitesse des moteurs brushless et l’angle des servo-moteurs pour le ramener sur le plan horizontal le plus rapidement possible. Cependant cette vitesse d’exécution et la précision du retour est déterminée à l’aide de constantes (de proportionnalité, d’intégration et de dérivé). Ces constantes sont pour l’instant choisie arbitrairement, elles devront surement être modifiées par la suite à l’aide des tests menés.

Nous avons ensuite mis la partie commande Bluetooth dans le programme du PID pour pouvoir commander le bicoptère à l’aide du téléphone portable afin de procéder aux premiers tests. Le problème est que le Bluetooth établit une connexion instable entre le téléphone et le système donc les consignes sont données par saccades ce qui produit des à coups au niveau des réactions des moteurs (brushless et des servo-moteurs). Les tests n’ont donc pas pu être concluants du tout. De plus un moteur brushless semble être défectueux, j’ai donc envoyé un mail au professeur pour commander d’autres moteurs brushless.

Voici le lien de la vidéo expliquant ce qu’il se passe : https://www.youtube.com/watch?v=Gy4HInOOm9E

J’attends donc la rentrée pour pouvoir récupérer une télécommande ainsi que les moteurs que nous avons commandés.

Lors de la séance du 06/02/2019 j’ai récupéré la télécommande, j’ai donc intégré le récepteur au bicoptère puis je me suis inspiré d’un programme trouvé sur internet pour faire le programme de la télécommande et connecter canaux à la carte Arduino.


Puis en fonction de chaque information envoyée par la télécommande il faut associer une action (vitesse des moteurs brushless et/ou changement d’angle des servo-moteurs). Ceci m’a clairement pris les 3h, même s’il reste encore quelques couacs dans le programme (qui fonctionne !!), au niveau du ROLL la consigne envoyée n’est absolument pas optimale. Il faudra réfléchir à une meilleure solution.

J’ai ensuite intégré le programme du PID au programme de la télécommande.

J’ai fini par faire quelques tests pour me rendre compte que ce problème de moteur m’handicape toujours et aussi que les moteurs ne semblent pas assez puissants car même à quasi-pleine puissance le bicoptère ne s’est pas élevé.

En voici la preuve : https://www.youtube.com/watch?v=lbTwwCgskWw&feature=youtu.be

Il faut donc regarder comment on peut gagner du poids et/ou commander des moteurs brushless plus puissants.

Update journée du 07/02/2019 après une bonne nuit de réflexion durant le sommeil j’ai trouvé comment résoudre ce problème de consigne envoyée pour la commande du ROLL, c’est donc après avoir passé quelques dizaines de minutes passées à modifier le code que les tests ont étés concluants, les moteurs augmentent bien progressivement suivant le coté demandé. Cependant les moteurs étant toujours défectueux je ne peux pas opérer de réel test de vol car un des deux moteurs est totalement imprévisible, je risque donc d’endommager le bicoptère.

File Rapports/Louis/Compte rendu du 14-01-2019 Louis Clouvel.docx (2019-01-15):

Compte rendu du 14-01-2019 :

Aujourd’hui j’ai terminé le système d’orientation des moteurs brushless en raccourcissant chaque axe, et en perçant le palonnier de l’axe moteur gauche.

Cela m’a pris une bonne heure car il fallait reproduire chaque action symétriquement des deux côtés pour un soucis d’équilibre global du système.

Voici le bicoptère dans sa version finale au point de vu mécanisme d’orientation :


Oui, ce sont bien des cure-dents en bois qui permettent de rendre le palonnier moteur solidaire de l’axe, la solution « technologique » pourrait bien être celle retenue définitivement ! 😊

Ensuite nous avons fait les branchements appropriés de la carte Arduino Nano et les ESCs pour pouvoir tenter un premier décollage sans contrôle de stabilité ni même orientation des moteurs, simplement pour vérifier que la puissance des deux moteurs était suffisante pour faire décoller l’ensemble.

Forcément la carte Arduino étant branchée à mon ordinateur, la batterie n’étant pas fixée sur le squelette mais simplement posée sur le plan inférieur et le fait que l’on tente un décollage sur notre paillasse (déjà bien encombrée de deux ordinateurs), on savait d’avance que l’on ne pourrait décoller que de quelques centimètres…

Il est maintenant temps de téléverser le programme qui permettrai de commander les moteurs brushless via Bluetooth.

On fait alors un premier test sans mettre les hélices et on voit qu’il semble y avoir un problème dans notre code car lorsque l’on fait augmenter la valeur envoyée via Bluetooth, à partir d’une certaine valeur, le moteur change de sens de rotation, ce qui pourrait être plus que problématique en vol !!

Vite une retouche dans le code, on téléverse à nouveau, et BAM, tout à l’air de fonctionner !!!

……Ah non j’oubliais, on a toujours ce satané moteur gauche qui tourne moins vite que le moteur droit... Je décide alors de lui envoyer une valeur toujours un peu plus importante que le moteur droit, oui c’est du bidouillage mais ça peut marcher, je vous rappelle que le test de décollage est uniquement pour nous assurer que la puissance des moteurs est suffisante !

Une nouvelle modification dans le code, aller s’en est assez, cette fois ci plus de tests préliminaires, on met les hélices et on tente le décollage.

Et voici le premier test de décollage en vidéo : https://www.youtube.com/watch?v=y_h1CxXEg0Y&feature=youtu.be

Parfait, à la moitié de la puissance des moteurs, le drone se soulève !!

Les moteurs sont donc largement assez puissants pour lui permettre de voler.

Cependant il va falloir changer le moteur de gauche sinon nous auront de gros problèmes pour la stabilisation.

Nous avons passé le reste de la séance à essayer de charger une seconde librairie de Timer sur Arduino car lorsque l’on veut faire fonctionner les moteurs brushless en même temps que les servo-moteurs il y a un conflit de Timer.

A la fin de la séance nous avons fait la petite soutenance de mi-projet où nous avons eu quelques couacs lors des démonstrations de l’orientation des axes moteur et de la commande des moteurs brushless.

Clouvel Louis

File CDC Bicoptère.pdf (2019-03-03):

Fonction(s) Contrainte(s)
Description | Critère(s)
FC1: Autonomie | Le système doit pouvoir fonctionner à l'aide d'une batterie avec un temps de vol de 10 à 15min
FC2: Résister à l'environnement | Le système doit pouvoir résister aux chutes éventuelles sans trop se dégrader
FC3: Être réalisable à l'école | Avec les moyens techniques mis à notre disposition Dans le temps imparti (environ 3 mois)
FC4: Sécurité | La mise en route des moteurs doit se faire par une manipulation supplémentaire

Cahier des charges
Fonction(s) Principale(s)
Description | Critère(s)
FP1: voler stablement | Le sytème doit être capable de se maintenir dans une position fixe

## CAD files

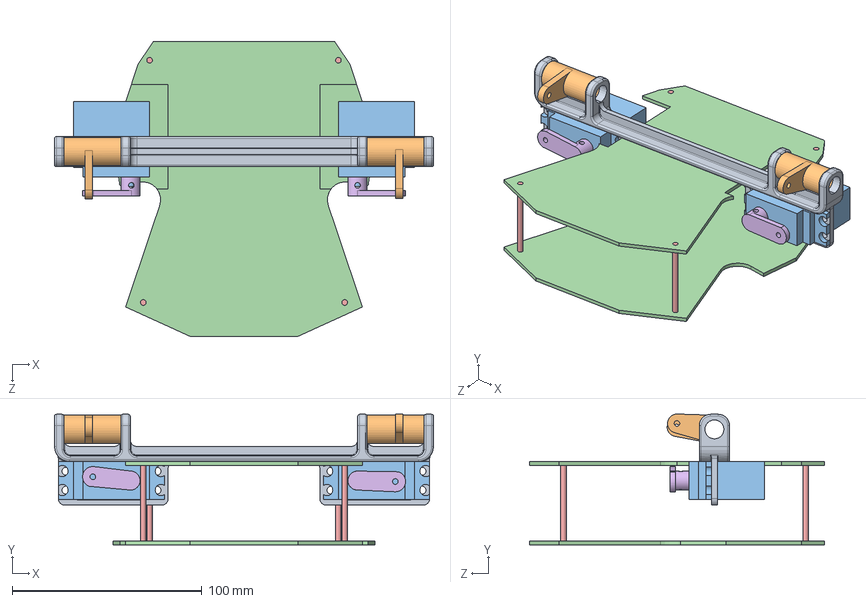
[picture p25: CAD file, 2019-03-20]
CAO/Drone complet.SLDASM
200.0 x 69.1 x 155.5 mm
Chassisfinal
Palonnier arbre moteur x 2
Servo.step x 2
squelette drone
Entretoise squelette x 4
bout abre moteur x 2

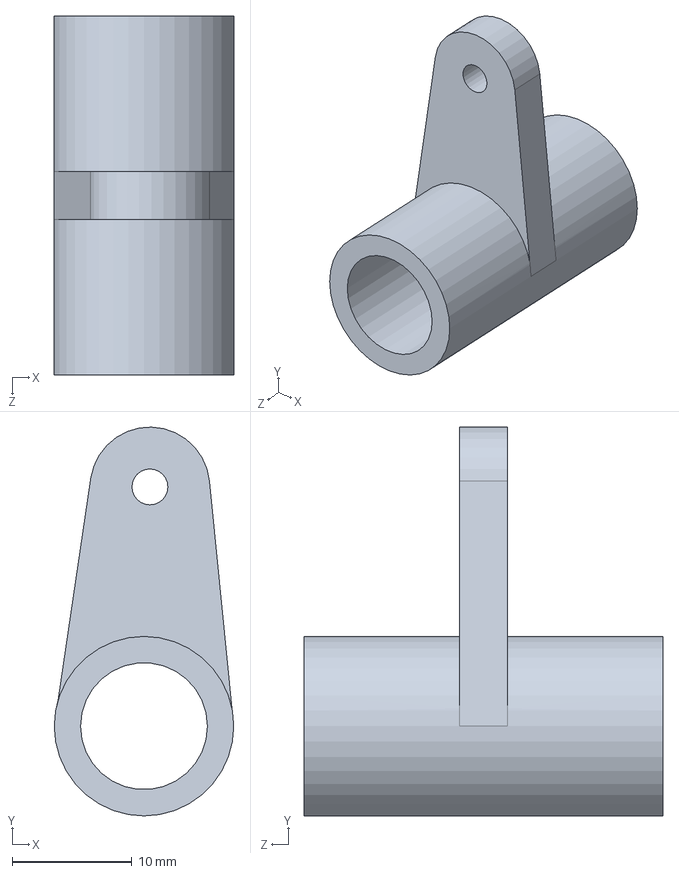
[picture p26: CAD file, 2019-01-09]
CAO/Palonnier arbre moteur.SLDPRT
15.0 x 32.5 x 30.0 mm

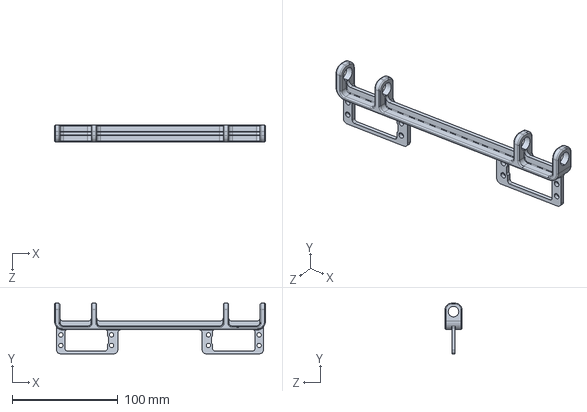
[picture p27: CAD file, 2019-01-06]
CAO/Chassisfinal.SLDPRT
200.0 x 48.0 x 16.0 mm

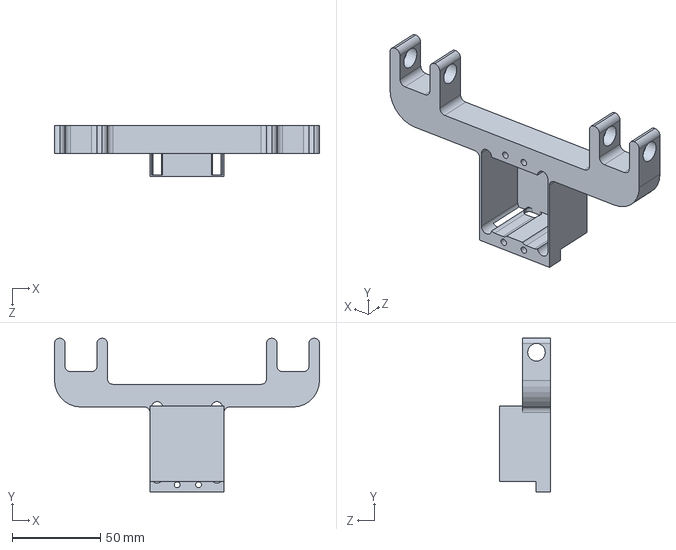
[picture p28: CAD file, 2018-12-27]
CAO/1er jet chassis.SLDPRT
150.0 x 87.0 x 29.0 mm

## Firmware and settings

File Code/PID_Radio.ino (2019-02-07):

#include <Servo.h>
#include <Wire.h>
#define CHANNEL1 0
#define CHANNEL2 1
#define CHANNEL3 2
#define CHANNEL4 3

#define YAW      0
#define PITCH    1
#define ROLL     2
#define THROTTLE 3
Servo right_prop;
Servo left_prop;
Servo right_servo;
Servo left_servo;
//PID variable
int16_t Acc_rawX, Acc_rawY, Acc_rawZ,Gyr_rawX, Gyr_rawY, Gyr_rawZ;
 float Acceleration_angleY, Acceleration_angleX;
float Gyro_angleY,Gyro_angleX;
float Total_angleY,Total_angleX;
float elapsedTime, time, timePrev;
float desired_angle = 0;
double throttle=1000;//initial value of throttle to the motors
double PITCHcom=1500; //initial value of angle to the servos
double ROLLcom=1500;
double ROLLvalright=1500;
double ROLLvalleft=1500;
double YAWcom=1500;
int i;
float rad_to_deg = 180/3.141592654;

float PID, pwmLeft, pwmRight, error, previous_error;
float PIDX, pwmPITCHright, pwmPITCHleft, errorX, previous_errorX;
float pid_pX=0;
float pid_iX=0;
float pid_dX=0;
float pid_p=0;
float pid_i=0;
float pid_d=0;
//PID constants
double kp=3.55;//3.55
double ki=0.005;//0.003
double kd=2.05;//2.05


// end of PID variable


volatile unsigned long current_time;
volatile unsigned long timer[4];

// Previous state of each channel (HIGH or LOW)
volatile byte previous_state[4];

// Duration of the pulse on each channel in µs (must be within 1000µs & 2000µs)
volatile unsigned int pulse_duration[4] = {1500, 1500, 1000, 1500};

int mode_mapping[4];

/**
 * Setup routine.
 *
 * @return void
 */
void setup()
{
    Wire.begin(); //begin the wire comunication pour l'accéléromètre
    Wire.beginTransmission(0x68);
    Wire.write(0x6B);
    Wire.write(0);
    Wire.endTransmission(true);
    Serial.begin(9600);

    // Customize mapping of controls: set here which command is on wich channel.
    mode_mapping[YAW]      = CHANNEL4;
    mode_mapping[PITCH]    = CHANNEL2;
    mode_mapping[ROLL]     = CHANNEL1;
    mode_mapping[THROTTLE] = CHANNEL3;

    PCICR  |= (1 << PCIE0);  //Set PCIE0 to enable PCMSK0 scan.
    PCMSK0 |= (1 << PCINT0); //Set PCINT0 (digital input 8) to trigger an interrupt on state change.
    PCMSK0 |= (1 << PCINT1); //Set PCINT1 (digital input 9)to trigger an interrupt on state change.
    PCMSK0 |= (1 << PCINT2); //Set PCINT2 (digital input 10)to trigger an interrupt on state change.
    PCMSK0 |= (1 << PCINT3); //Set PCINT3 (digital input 11)to trigger an interrupt on state change.

    right_prop.attach(5); //attach the right motor to pin 5
    left_prop.attach(6);  //attach the left motor to pin 6
    right_servo.attach(3); //attach the right servo to pin 3
    left_servo.attach(2);  //attach the left servo to pin 2
    time = millis(); //Start counting time in milliseconds

    /*In order to start up the ESCs we have to send a min value
   * of PWM to them before connecting the battery. Otherwise
   * the ESCs won't start up or enter in the configure mode.
   * The min value is 1000us and max is 2000us, REMEMBER!*/
  left_prop.writeMicroseconds(1000); 
  right_prop.writeMicroseconds(1000);
  delay(7000); /*Give some delay, 7s, to have time to connect
                *the propellers and let everything start up*/ 
}

/**
 * Main loop routine.
 *
 * @return void
 */
void loop()
{
    
    /*dumpChannels();*/
    timePrev = time;  // the previous time is stored before the actual time read
    time = millis();  // actual time read
    elapsedTime = (time - timePrev) / 1000; 

    /*The tiemStep is the time that elapsed since the previous loop. 
   * This is the value that we will use in the formulas as "elapsedTime" 
   * in seconds. We work in ms so we haveto divide the value by 1000 
   to obtain seconds*/

  /*Reed the values that the accelerometre gives.
   * We know that the slave adress for this IMU is 0x68 in
   * hexadecimal. For that in the RequestFrom and the 
   * begin functions we have to put this value.*/
   
     Wire.beginTransmission(0x68);
     Wire.write(0x3B); //Ask for the 0x3B register- correspond to AcX
     Wire.endTransmission(false);
     Wire.requestFrom(0x68,6,true); 
   
   /*We have asked for the 0x3B register. The IMU will send a brust of register.
    * The amount of register to read is specify in the requestFrom function.
    * In this case we request 6 registers. Each value of acceleration is made out of
    * two 8bits registers, low values and high values. For that we request the 6 of them  
    * and just make then sum of each pair. For that we shift to the left the high values 
    * register (<<) and make an or (|) operation to add the low values.*/
    
     Acc_rawX=Wire.read()<<8|Wire.read(); //each value needs two registres
     Acc_rawY=Wire.read()<<8|Wire.read();
     Acc_rawZ=Wire.read()<<8|Wire.read();

 
    /*///This is the part where you need to calculate the angles using Euler equations///*/
    
    /* - Now, to obtain the values of acceleration in "g" units we first have to divide the raw   
     * values that we have just read by 16384.0 because that is the value that the MPU6050 
     * datasheet gives us.*/
    /* - Next we have to calculate the radian to degree value by dividing 180º by the PI number
    * which is 3.141592654 and store this value in the rad_to_deg variable. In order to not have
    * to calculate this value in each loop we have done that just once before the setup void.
    */

    /* Now we can apply the Euler formula. The atan will calculate the arctangent. The
     *  pow(a,b) will elevate the a value to the b power. And finnaly sqrt function
     *  will calculate the rooth square.*/
     /*---X---*/
     Acceleration_angleY = atan((Acc_rawY/16384.0)/sqrt(pow((Acc_rawX/16384.0),2) + pow((Acc_rawZ/16384.0),2)))*rad_to_deg;
     /*---Y---*/
     Acceleration_angleX = atan(-1*(Acc_rawX/16384.0)/sqrt(pow((Acc_rawY/16384.0),2) + pow((Acc_rawZ/16384.0),2)))*rad_to_deg;
     
   /*Now we read the Gyro data in the same way as the Acc data. The adress for the
    * gyro data starts at 0x43. We can see this adresses if we look at the register map
    * of the MPU6050. In this case we request just 4 values. W don¡t want the gyro for 
    * the Z axis (YAW).*/
    /*Now we read the Gyro data in the same way as the Acc data. The adress for the
    * gyro data starts at 0x43. We can see this adresses if we look at the register map
    * of the MPU6050. In this case we request just 4 values. W don¡t want the gyro for 
    * the Z axis (YAW).*/
    
   Wire.beginTransmission(0x68);
   Wire.write(0x43); //Gyro data first adress
   Wire.endTransmission(false);
   Wire.requestFrom(0x68,4,true); //Just 4 registers
   
   Gyr_rawX=Wire.read()<<8|Wire.read(); //Once again we shif and sum
   Gyr_rawY=Wire.read()<<8|Wire.read();
 
   /*Now in order to obtain the gyro data in degrees/seconda we have to divide first
   the raw value by 131 because that's the value that the datasheet gives us*/

   /*---X---*/
   Gyro_angleX = Gyr_rawX/131.0; 
   /*---Y---*/
   Gyro_angleY = Gyr_rawY/131.0;
    /*---X axis angle---*/
   Total_angleX = 0.98 *(Total_angleX + Gyro_angleY*elapsedTime) + 0.02*Acceleration_angleX;
   /*---Y axis angle---*/
   Total_angleY = 0.98 *(Total_angleY + Gyro_angleX*elapsedTime) + 0.02*Acceleration_angleY;
   
   /*Now we have our angles in degree and values from -10º0 to 100º aprox*/
   /*///////////////////////////P I D///////////////////////////////////*/
/*Remember that for the balance we will use just one axis. I've choose the x angle
to implement the PID with. That means that the x axis of the IMU has to be paralel to
the balance*/

/*First calculate the error between the desired angle and 
*the real measured angle*/
error = Total_angleY - desired_angle;
errorX = Total_angleX - desired_angle;    
/*Next the proportional value of the PID is just a proportional constant
*multiplied by the error*/
pid_pX = kp*errorX;
pid_p = kp*error;

/*The integral part should only act if we are close to the
desired position but we want to fine tune the error. That's
why I've made a if operation for an error between -2 and 2 degree.
To integrate we just sum the previous integral value with the
error multiplied by  the integral constant. This will integrate (increase)
the value each loop till we reach the 0 point*/
if(-3 <error <3)
{
  pid_i = pid_i+(ki*error);  
}


if(-3 <errorX <3)
{
  pid_iX = pid_iX+(ki*errorX);  
}
/*The last part is the derivate. The derivate acts upon the speed of the error.
As we know the speed is the amount of error that produced in a certain amount of
time divided by that time. For taht we will use a variable called previous_error.
We substract that value from the actual error and divide all by the elapsed time. 
Finnaly we multiply the result by the derivate constant*/

pid_d = kd*((error - previous_error)/elapsedTime);
pid_dX = kd*((errorX - previous_errorX)/elapsedTime);
/*The final PID values is the sum of each of this 3 parts*/
PID = pid_p + pid_i + pid_d;
PIDX = pid_pX + pid_iX + pid_dX;
/*We know taht the min value of PWM signal is 1000us and the max is 2000. So that
tells us that the PID value can/s oscilate more than -1000 and 1000 because when we
have a value of 2000us the maximum value taht we could sybstract is 1000 and when
we have a value of 1000us for the PWM sihnal, the maximum value that we could add is 1000
to reach the maximum 2000us*/
if(PID < -1000)
{
  PID=-1000;
}
if(PID > 1000)
{
  PID=1000;
}
if(PIDX < -1000)
{
  PIDX=-1000;
}
if(PIDX > 1000)
{
  PIDX=1000;
}
/*Finnaly we calculate the PWM width. We sum the desired throttle and the PID value*/
throttle=pulse_duration[CHANNEL3];
PITCHcom = pulse_duration[CHANNEL2]; 

ROLLcom =pulse_duration[CHANNEL1];
if(ROLLcom>1700){
  ROLLcom=1700;
}
if(ROLLcom<1300){
  ROLLcom=1300;
}

YAWcom = pulse_duration[CHANNEL4];
if(YAWcom>1700){
  YAWcom=1700;
}
if(YAWcom<1300){
  YAWcom=1300;
}
pwmLeft = throttle + PID;
pwmRight = throttle - PID;
pwmPITCHright = PITCHcom - PIDX - 195;
pwmPITCHleft =(3000- PITCHcom) + PIDX + 30;

/*Once again we map the PWM values to be sure that we won't pass the min
and max values. Yes, we've already maped the PID values. But for example, for 
throttle value of 1300, if we sum the max PID value we would have 2300us and
that will mess up the ESC.*/
//Right
if(pwmRight < 1000)
{
  pwmRight= 1000;
}
if(pwmRight > 2000)
{
  pwmRight=2000;
}
//Left
if(pwmLeft < 1000)
{
  pwmLeft= 1000;
}
if(pwmLeft > 2000)
{
  pwmLeft=2000;
}
//PITCHright
if(pwmPITCHright < 1015)
{
  pwmPITCHright= 1015;
}
if(pwmPITCHright > 1770)
{
  pwmPITCHright=1770;
}
//PITCHleft
if(pwmPITCHleft < 1027)
{
  pwmPITCHleft= 1027;
}
if(pwmPITCHleft > 1910)
{
  pwmPITCHleft=1910;
}
/*Finnaly using the servo function we create the PWM pulses with the calculated
width for each pulse*/
left_prop.writeMicroseconds(pwmLeft);
right_prop.writeMicroseconds(pwmRight);
right_servo.writeMicroseconds(pwmPITCHright);
left_servo.writeMicroseconds(pwmPITCHleft);

if((YAWcom>1480)&&(YAWcom<1520)){
  right_servo.writeMicroseconds(pwmPITCHright);
  left_servo.writeMicroseconds(pwmPITCHleft);
  }
  else{
    right_servo.writeMicroseconds(YAWcom -195);
    left_servo.writeMicroseconds(YAWcom + 30);
  }

  
  ROLLvalleft=throttle+(ROLLcom-1500);
  ROLLvalright=throttle-(ROLLcom-1500);
 
  if(ROLLvalleft<1000){
    ROLLvalleft=1000;
  }
  if(ROLLvalleft>2000){
    ROLLvalleft=2000;
  }
  
  if(ROLLvalright<1000){
    ROLLvalright=1000;
  }

  if(ROLLvalright>2000){
    ROLLvalright=2000;
  }
   
  if((ROLLcom>1480)&&(ROLLcom<1520)){
    left_prop.writeMicroseconds(pwmLeft);
    right_prop.writeMicroseconds(pwmRight);
   }
   
  else{
    if(ROLLcom>1520){
        left_prop.writeMicroseconds(ROLLvalleft);
        right_prop.writeMicroseconds(pwmRight);
    }
    if(ROLLcom<1480){
        left_prop.writeMicroseconds(pwmLeft);
        right_prop.writeMicroseconds(ROLLvalright);
    }
  }
  
previous_error = error; //Remember to store the previous error.
previous_errorX = errorX;
   
}

/**
 * Print received instruction for each channel in the serial port for debug.
 *
 * @return void
 */
/*void dumpChannels()
{
    for (int i = CHANNEL1; i <= CHANNEL4; i++) {
        Serial.print("Channel ");
        Serial.print(i+1);
        Serial.print(": ");
        Serial.print(pulse_duration[i]);
        Serial.print("\t");
    }
    Serial.print("\n");
}*/

/**
 * This Interrupt Sub Routine is called each time input 8, 9, 10 or 11 changed state.
 * Read the receiver signals in order to get flight instructions.
 *
 * This routine must be as fast as possible to prevent main program to be messed up.
 * The trick here is to use port registers to read pin state.
 * Doing (PINB & B00000001) is the same as digitalRead(8) with the advantage of using less CPU loops.
 * It is less conveniant but more efficient, which is the most important here.
 *
 * @see https://www.arduino.cc/en/Reference/PortManipulation
 */
ISR(PCINT0_vect)
{
    current_time = micros();

    // Channel 1 -------------------------------------------------
    if (PINB & B00000001) {                                        // Is input 8 high ?
        if (previous_state[CHANNEL1] == LOW) {                     // Input 8 changed from 0 to 1 (rising edge)
            previous_state[CHANNEL1] = HIGH;                       // Save current state
            timer[CHANNEL1]          = current_time;               // Start timer
        }
    } else if(previous_state[CHANNEL1] == HIGH) {                  // Input 8 changed from 1 to 0 (falling edge)
        previous_state[CHANNEL1] = LOW;                            // Save current state
        pulse_duration[CHANNEL1] = current_time - timer[CHANNEL1]; // Stop timer & calculate pulse duration
    }

    // Channel 2 -------------------------------------------------
    if (PINB & B00000010) {                                        // Is input 9 high ?
        if (previous_state[CHANNEL2] == LOW) {                     // Input 9 changed from 0 to 1 (rising edge)
            previous_state[CHANNEL2] = HIGH;                       // Save current state
            timer[CHANNEL2]          = current_time;               // Start timer
        }
    } else if(previous_state[CHANNEL2] == HIGH) {                  // Input 9 changed from 1 to 0 (falling edge)
        previous_state[CHANNEL2] = LOW;                            // Save current state
        pulse_duration[CHANNEL2] = current_time - timer[CHANNEL2]; // Stop timer & calculate pulse duration
    }

    // Channel 3 -------------------------------------------------
    if (PINB & B00000100) {                                        // Is input 10 high ?
        if (previous_state[CHANNEL3] == LOW) {                     // Input 10 changed from 0 to 1 (rising edge)
            previous_state[CHANNEL3] = HIGH;                       // Save current state
            timer[CHANNEL3]          = current_time;               // Start timer
        }
    } else if(previous_state[CHANNEL3] == HIGH) {                  // Input 10 changed from 1 to 0 (falling edge)
        previous_state[CHANNEL3] = LOW;                            // Save current state
        pulse_duration[CHANNEL3] = current_time - timer[CHANNEL3]; // Stop timer & calculate pulse duration
    }

    // Channel 4 -------------------------------------------------
    if (PINB & B00001000) {                                        // Is input 11 high ?
        if (previous_state[CHANNEL4] == LOW) {                     // Input 11 changed from 0 to 1 (rising edge)
            previous_state[CHANNEL4] = HIGH;                       // Save current state
            timer[CHANNEL4]          = current_time;               // Start timer
        }
    } else if(previous_state[CHANNEL4] == HIGH) {                  // Input 11 changed from 1 to 0 (falling edge)
        previous_state[CHANNEL4] = LOW;                            // Save current state
        pulse_duration[CHANNEL4] = current_time - timer[CHANNEL4]; // Stop timer & calculate pulse duration
    }
}

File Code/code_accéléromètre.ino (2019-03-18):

#include <Wire.h>
const int MPU_addr = 0x68;
float Acc_X, Acc_Y, Acc_Z; 
float angle_x,angle_y,angle_z;

void setup() {
  // put your setup code here, to run once:
  Serial.begin(9600);
  Wire.begin(); 
  Wire.beginTransmission(MPU_addr); 
  Wire.write(0x6B); 
  Wire.write(0);
  Wire.endTransmission(); 

}

void loop() {
  // put your main code here, to run repeatedly:
  Wire.beginTransmission(0x68);
  Wire.write(0x3B);
  Wire.endTransmission(false); 
  Wire.requestFrom(0x68,6,true);

  Acc_X=(Wire.read()<<8|Wire.read());
  Acc_Y=(Wire.read()<<8|Wire.read());
  Acc_Z=(Wire.read()<<8|Wire.read()); 

  angle_x = (atan((Acc_X/16384) / sqrt(pow((Acc_Y/16384),2) + pow((Acc_Z/16384),2))) * 180/PI);
  angle_y = (atan((Acc_Y/16384) / sqrt(pow((Acc_X/16384),2) + pow((Acc_Z/16384),2))) * 180/PI);
  Serial.print(angle_x);
  Serial.print("  ");
  Serial.println(angle_y);
  Serial.print("  ");

  


}
